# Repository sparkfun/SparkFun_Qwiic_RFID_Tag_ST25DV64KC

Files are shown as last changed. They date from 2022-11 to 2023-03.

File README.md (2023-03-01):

SparkFun Qwiic Dynamic NFC/RFID Tag
===================================

SparkFun Qwiic Dynamic NFC/RFID Tag (https://www.sparkfun.com/products/21274)

[SparkFun Qwiic Dynamic NFC/RFID Tag (SEN-21274)](https://www.sparkfun.com/products/21274)

The STMicroelectronics ST25DV dynamic Near Frequency Communication / Radio Frequency Identification tag ICs are awesome! The ST25DV64KC offers 64-kBit (8-kBytes) of EEPROM memory which can be accessed over both I2C and RF (NFC)! It's a state-of-the-art tag which conforms to ISO/IEC 15693 or NFC Forum Type 5 recommendations. You can read and write the tag's memory using NFC even while the tag is powered down or disconnected!

The EEPROM memory can be divided into four areas, each of which can have different levels of protection applied. Want to store your data so everyone has read and write access over both I2C and RF? You can do that. In fact, that's the default! Want to store your data in an area which can only be read if you know the password, and cannot be written to (via RF)? You can do that too!

Our [Arduino Library](https://github.com/sparkfun/SparkFun_ST25DV64KC_Arduino_Library) provides all of the methods you need to read and write the user memory, control the read and write permissions, alter the area sizes and apply password control. Not only that! We've included extra methods which will let you read and write NDEF (NFC Forum Data Exchange Format) URI, WiFi and Text records which your smart phone can understand!

Repository Contents
-------------------

* /Documents - Data sheets, additional product information
* /Hardware - Eagle design files (.brd, .sch)
* /Production - Production panel files (.brd)

Documentation
-------------

* **[Hookup Guide](https://learn.sparkfun.com/tutorials/qwiic-dynamic-nfcrfid-tag-hookup-guide)** - A basic Hookup Guide for the SparkFun Qwiic Dynamic NFC/RFID Tag.
* **[ST25DV64KC Arduino Library](https://github.com/sparkfun/SparkFun_ST25DV64KC_Arduino_Library)** - Arduino library for the ST25DV64KC Qwiic Dynamic NFC/RFID Tag.
* **[ST25DV64KC Arduino Library Documentation](https://docs.sparkfun.com/SparkFun_ST25DV64KC_Arduino_Library/)** - A full library use overview, API reference guide and key example walk-through.

Product Versions
----------------

* **[SEN-21274](https://www.sparkfun.com/products/21274)** - Initial SparkFun version release
* **[SPX-19035](https://www.sparkfun.com/products/19035)** - Initial SparkX version release

License Information
-------------------

This product is _**open source**_! 

Please review the LICENSE.md file for license information. 

If you have any questions or concerns on licensing, please contact technical support on our [SparkFun forums](https://forum.sparkfun.com/viewforum.php?f=152).

Distributed as-is; no warranty is given.

- Your friends at SparkFun.

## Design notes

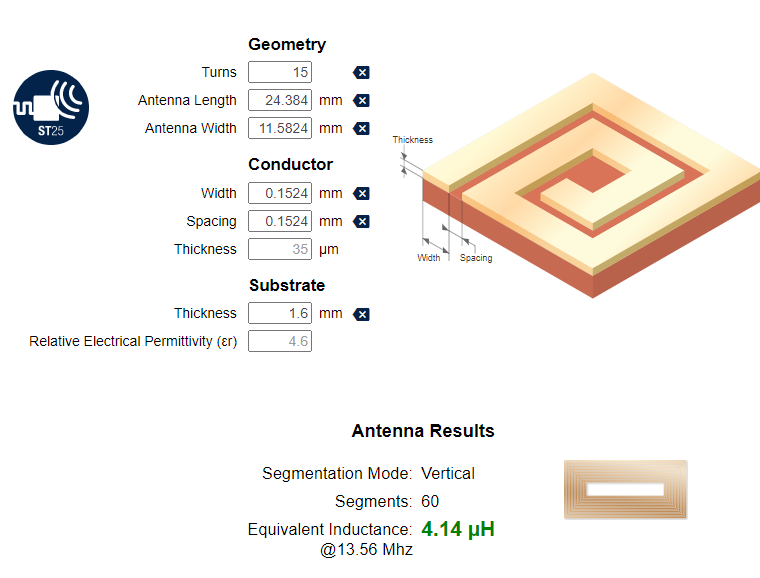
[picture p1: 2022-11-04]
Documents/Antenna_Design.png

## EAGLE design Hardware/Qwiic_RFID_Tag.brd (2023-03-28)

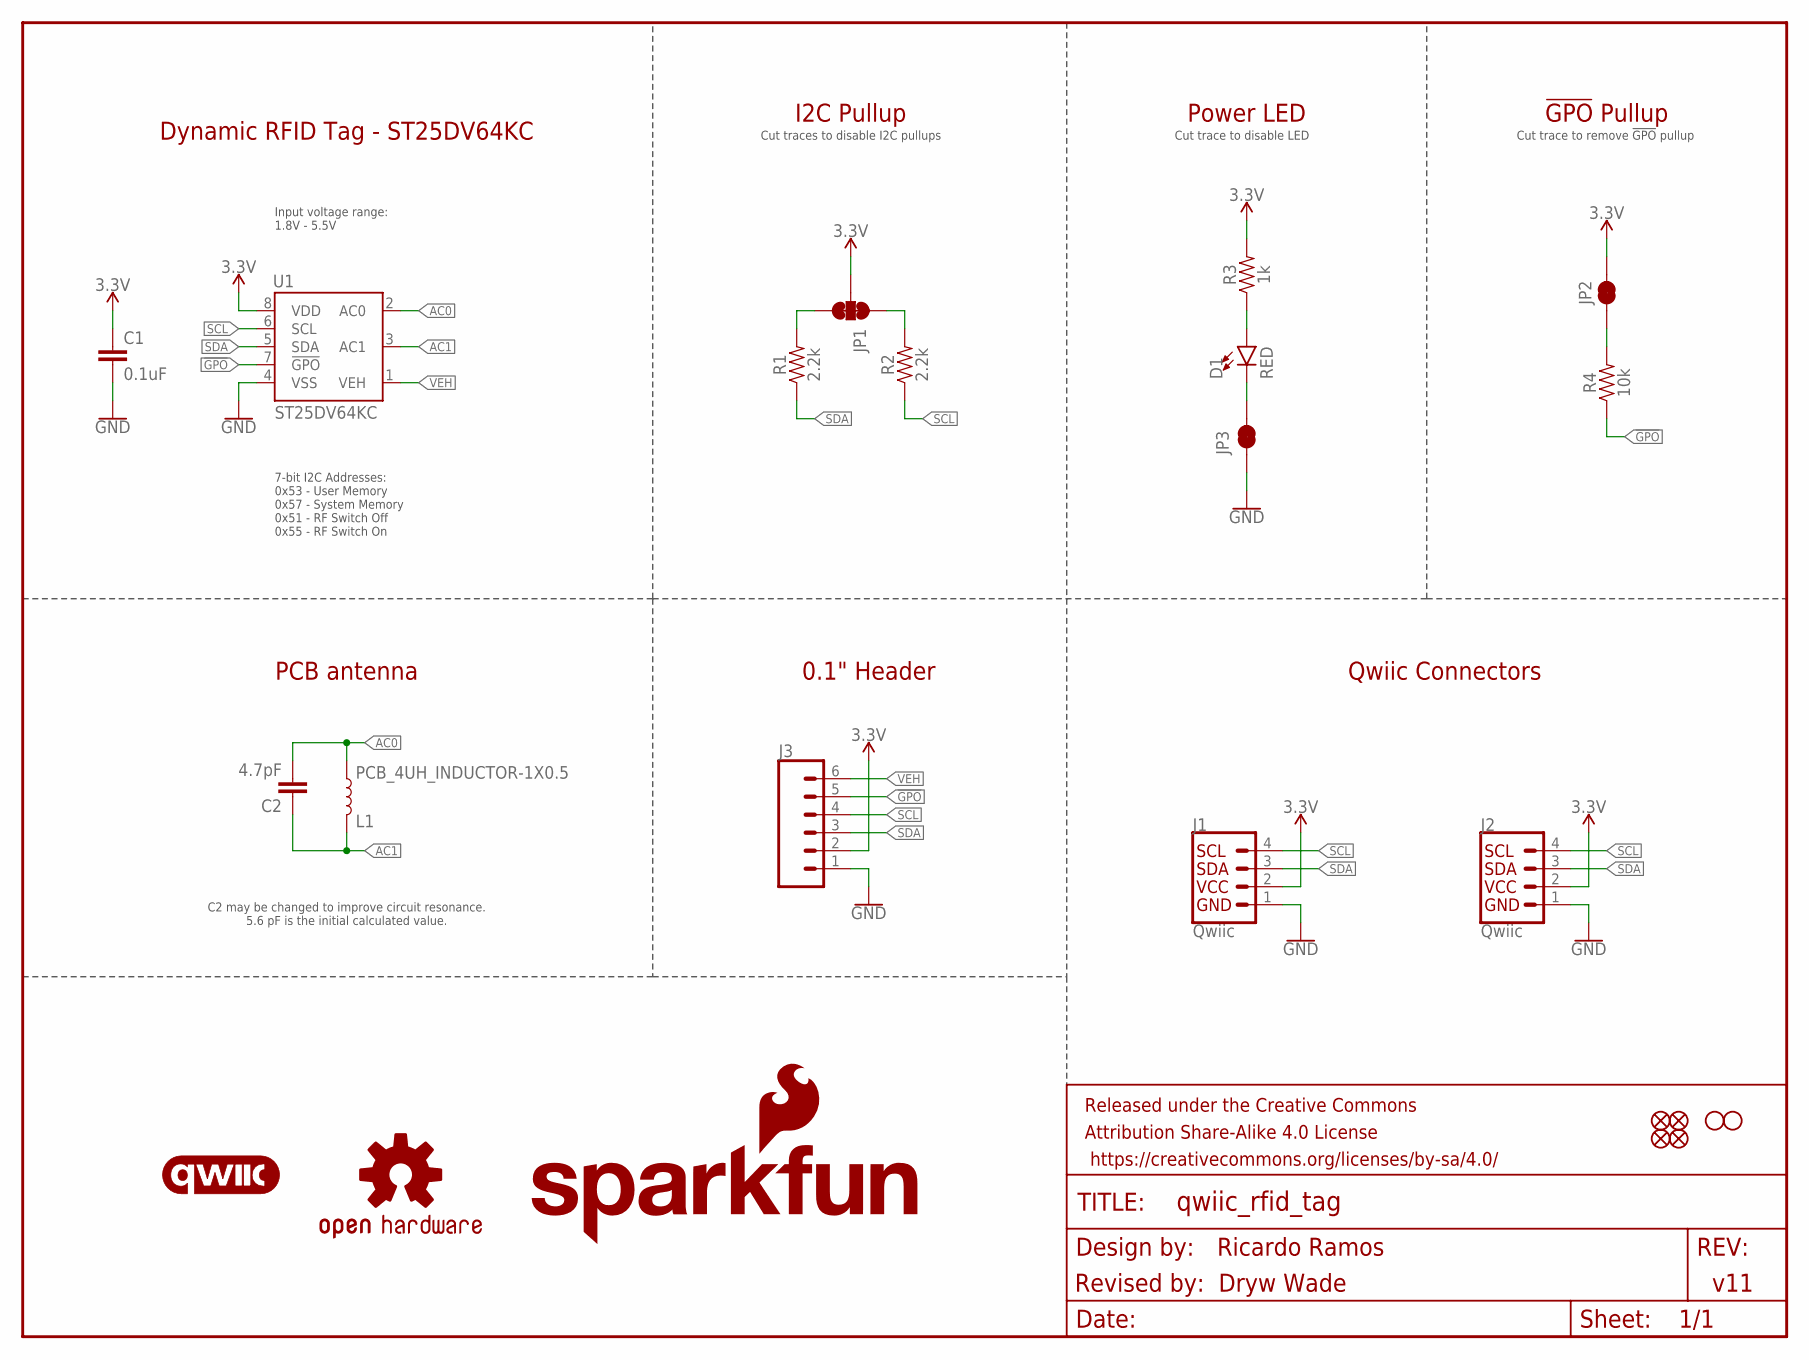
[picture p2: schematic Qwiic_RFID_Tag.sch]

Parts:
C1: 0.1uF; 0603
C2: 4.7pF; 0603
D1: RED; LED-0603
FD1, FD2, FD3, FD4: FIDUCIAL1X2; FIDUCIAL-1X2
FRAME2: FRAME-LETTER; CREATIVE_COMMONS
H3, H4: STAND-OFF
J1, J2: Qwiic; JST04_1MM_RA
J3: CONN_06NO_SILK_FEMALE_PTH; 1X06_NO_SILK
JP1: JUMPER-SMT_3_2-NC_TRACE_SILK; SMT-JUMPER_3_2-NC_TRACE_SILK
JP2, JP3: JUMPER-SMT_2_NC_TRACE_SILK; SMT-JUMPER_2_NC_TRACE_SILK
L1: PCB_4UH_INDUCTOR-1X0.5; PCB_4UH_INDUCTOR_1X0.5
LOGO1: OSHW-LOGOS; OSHW-LOGO-S
LOGO2: SFE_LOGO_NAME_FLAME.1_INCH; SFE_LOGO_NAME_FLAME_.1
LOGO3: QWIIC_LOGO_7MM; QWIIC_7MM
R1, R2: 2.2k; 0603
R3: 1k; 0603
R4: 10k; 0603
U1: ST25DV64KC; SO08

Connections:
3.3V: C1.1, J1.2, J2.2, J3.2, JP1.2, JP2.2, R3.2, U1.8 (VDD)
!GPO!: J3.5, R4.1, U1.7 (!GPO!)
AC0: C2.2, L1.IN2 (2), U1.2 (AC0)
AC1: C2.1, L1.IN1 (1), U1.3 (AC1)
GND: C1.2, J1.1, J2.1, J3.1, JP3.1, U1.4 (VSS)
unnamed: D1.C, JP3.2
unnamed: JP1.3, R1.2
unnamed: JP1.1, R2.2
unnamed: D1.A, R3.1
unnamed: JP2.1, R4.2
SCL: J1.4, J2.4, J3.4, R2.1, U1.6 (SCL)
SDA: J1.3, J2.3, J3.3, R1.1, U1.5 (SDA)
VEH: J3.6, U1.1 (VEH)

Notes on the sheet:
Qwiic Connectors
Cut trace to disable LED
Cut trace to remove !GPO! pullup
0.1" Header
PCB antenna
I2C Pullup
Power LED
!GPO! Pullup
Dynamic RFID Tag - ST25DV64KC
Cut traces to disable I2C pullups
C2 may be changed to improve circuit resonance. 5.6 pF is the initial calculated value.
v11
Ricardo Ramos
Revised by: Dryw Wade
7-bit I2C Addresses: 0x53 - User Memory 0x57 - System Memory 0x51 - RF Switch Off 0x55 - RF Switch On
Input voltage range: 1.8V - 5.5V

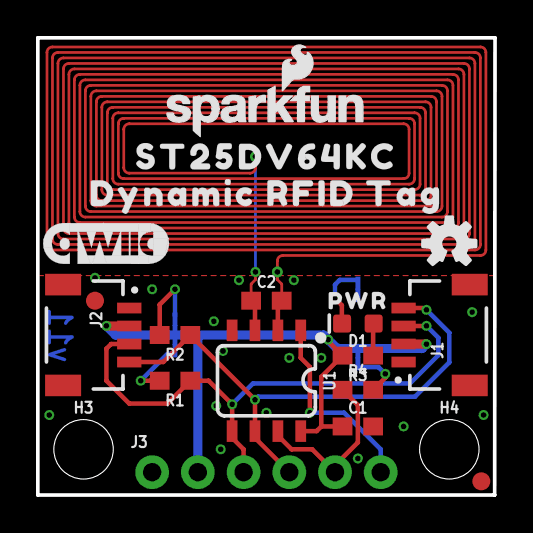
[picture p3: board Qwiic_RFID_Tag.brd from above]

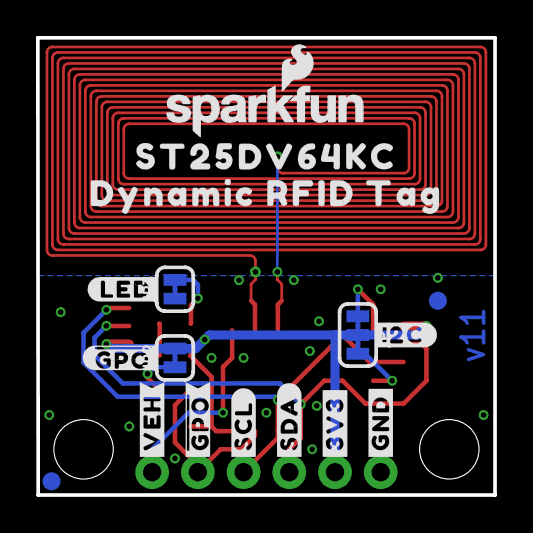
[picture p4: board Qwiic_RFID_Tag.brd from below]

Board: 2 copper layers, 25.4 x 25.4 mm, 40 parts (17 on the bottom side), 13 nets.

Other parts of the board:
LOGO4: SFE_LOGO_NAME_FLAME.1_INCH; SFE_LOGO_NAME_FLAME_.1
U$1: #I2C#0
U$3: #3V3#0
U$9: PWR11
U$10, U$11: DYNAMIC_RFID_TAG0
U$13, U$24: ST25DV64KC5984
U$16: ##GPO##9
U$17: #LED#10
U$18: #GND#4
U$20: #SDA#5
U$21: #SCL#6
U$22: ##GPO##8
U$23: #VEH#7

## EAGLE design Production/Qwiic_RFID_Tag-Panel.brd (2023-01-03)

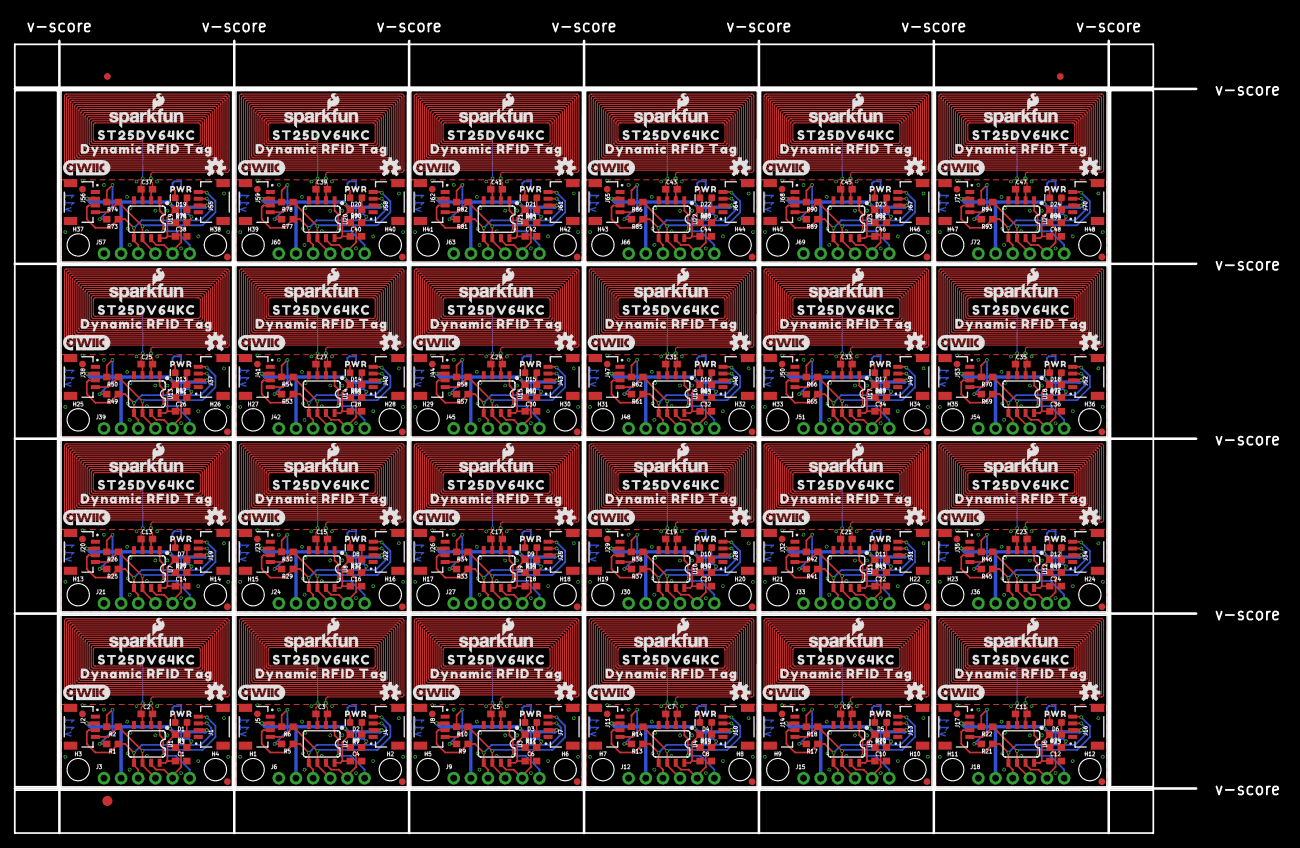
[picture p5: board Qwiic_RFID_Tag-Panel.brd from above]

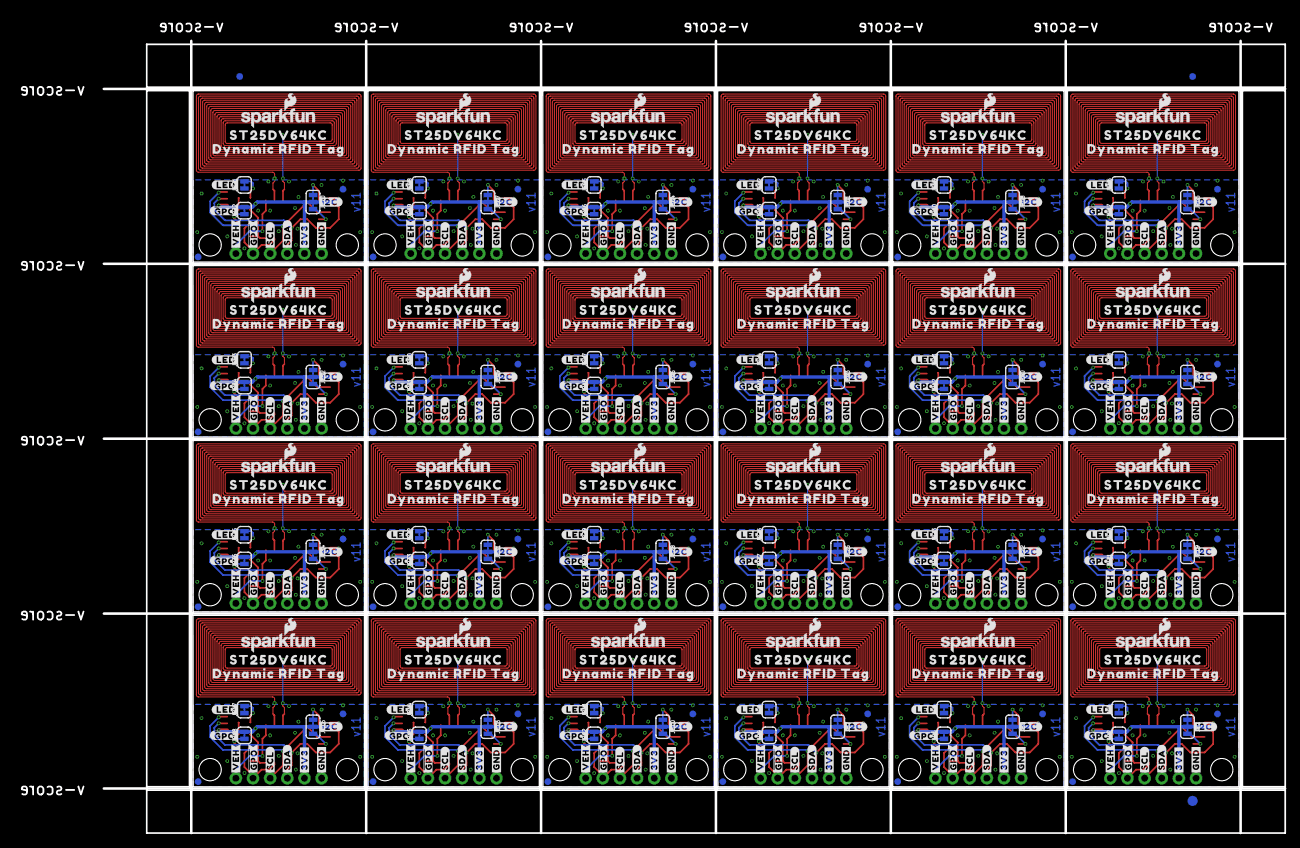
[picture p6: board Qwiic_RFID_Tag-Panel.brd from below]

Board: 2 copper layers, 175.0 x 117.3 mm, 942 parts (411 on the bottom side), 312 nets.

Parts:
C1, C4, C6, C8, C10, C12, C14, C16, C18, C20, C22, C24, C26, C28, C30, C32, C34, C36, C38, C40, C42, C44, C46, C48: 0.1uF; 0603
C2, C3, C5, C7, C9, C11, C13, C15, C17, C19, C21, C23, C25, C27, C29, C31, C33, C35, C37, C39, C41, C43, C45, C47: 4.7pF; 0603
D1, D2, D3, D4, D5, D6, D7, D8, D9, D10, D11, D12, D13, D14, D15, D16, D17, D18, D19, D20, D21, D22, D23, D24: RED; LED-0603
E$1, E$2, E$3, E$4: FIDUCIAL-1X2
E$5, E$6: FIDUCIAL-1.5X3
FD1, FD2, FD3, FD4, FD5, FD6, FD7, FD8, FD9, FD10, FD11, FD12, FD13, FD14, FD15, FD16, FD17, FD18, FD19, FD20, FD21, FD22, FD23, FD24, FD25, FD26, FD27, FD28, FD29, FD30, FD31, FD32, FD33, FD34, FD35, FD36, FD37, FD38, FD39, FD40, FD41, FD42, FD43, FD44, FD45, FD46, FD47, FD48, FD49, FD50, FD51, FD52, FD53, FD54, FD55, FD56, FD57, FD58, FD59, FD60, FD61, FD62, FD63, FD64, FD65, FD66, FD67, FD68, FD69, FD70, FD71, FD72, FD73, FD74, FD75, FD76, FD77, FD78, FD79, FD80, FD81, FD82, FD83, FD84, FD85, FD86, FD87, FD88, FD89, FD90, FD91, FD92, FD93, FD94, FD95, FD96: FIDUCIAL1X2; FIDUCIAL-1X2
H1, H2, H3, H4, H5, H6, H7, H8, H9, H10, H11, H12, H13, H14, H15, H16, H17, H18, H19, H20, H21, H22, H23, H24, H25, H26, H27, H28, H29, H30, H31, H32, H33, H34, H35, H36, H37, H38, H39, H40, H41, H42, H43, H44, H45, H46, H47, H48: STAND-OFF
J1, J2, J4, J5, J7, J8, J10, J11, J13, J14, J16, J17, J19, J20, J22, J23, J25, J26, J28, J29, J31, J32, J34, J35, J37, J38, J40, J41, J43, J44, J46, J47, J49, J50, J52, J53, J55, J56, J58, J59, J61, J62, J64, J65, J67, J68, J70, J71: Qwiic; JST04_1MM_RA
J3, J6, J9, J12, J15, J18, J21, J24, J27, J30, J33, J36, J39, J42, J45, J48, J51, J54, J57, J60, J63, J66, J69, J72: 1X06_NO_SILK
JP1, JP4, JP7, JP10, JP13, JP16, JP19, JP22, JP25, JP28, JP31, JP34, JP37, JP40, JP43, JP46, JP49, JP52, JP55, JP58, JP61, JP64, JP67, JP70: JUMPER-SMT_3_2-NC_TRACE_SILK; SMT-JUMPER_3_2-NC_TRACE_SILK
JP2, JP3, JP5, JP6, JP8, JP9, JP11, JP12, JP14, JP15, JP17, JP18, JP20, JP21, JP23, JP24, JP26, JP27, JP29, JP30, JP32, JP33, JP35, JP36, JP38, JP39, JP41, JP42, JP44, JP45, JP47, JP48, JP50, JP51, JP53, JP54, JP56, JP57, JP59, JP60, JP62, JP63, JP65, JP66, JP68, JP69, JP71, JP72: JUMPER-SMT_2_NC_TRACE_SILK; SMT-JUMPER_2_NC_TRACE_SILK
L1, L2, L3, L4, L5, L6, L7, L8, L9, L10, L11, L12, L13, L14, L15, L16, L17, L18, L19, L20, L21, L22, L23, L24: PCB_COIL_4UH_B
LOGO1, LOGO5, LOGO9, LOGO13, LOGO17, LOGO21, LOGO25, LOGO29, LOGO33, LOGO37, LOGO41, LOGO45, LOGO49, LOGO53, LOGO57, LOGO61, LOGO65, LOGO69, LOGO73, LOGO77, LOGO81, LOGO85, LOGO89, LOGO93: OSHW-LOGOS; OSHW-LOGO-S
LOGO2, LOGO4, LOGO7, LOGO8, LOGO11, LOGO12, LOGO15, LOGO16, LOGO19, LOGO20, LOGO23, LOGO24, LOGO27, LOGO28, LOGO31, LOGO32, LOGO35, LOGO36, LOGO39, LOGO40, LOGO43, LOGO44, LOGO47, LOGO48, LOGO51, LOGO52, LOGO55, LOGO56, LOGO59, LOGO60, LOGO63, LOGO64, LOGO67, LOGO68, LOGO71, LOGO72, LOGO75, LOGO76, LOGO79, LOGO80, LOGO83, LOGO84, LOGO87, LOGO88, LOGO91, LOGO92, LOGO95, LOGO96: SFE_LOGO_NAME_FLAME.1_INCH; SFE_LOGO_NAME_FLAME_.1
LOGO3, LOGO6, LOGO10, LOGO14, LOGO18, LOGO22, LOGO26, LOGO30, LOGO34, LOGO38, LOGO42, LOGO46, LOGO50, LOGO54, LOGO58, LOGO62, LOGO66, LOGO70, LOGO74, LOGO78, LOGO82, LOGO86, LOGO90, LOGO94: QWIIC_LOGO_7MM; QWIIC_7MM
R1, R2, R5, R6, R9, R10, R13, R14, R17, R18, R21, R22, R25, R26, R29, R30, R33, R34, R37, R38, R41, R42, R45, R46, R49, R50, R53, R54, R57, R58, R61, R62, R65, R66, R69, R70, R73, R74, R77, R78, R81, R82, R85, R86, R89, R90, R93, R94: 2.2k; 0603
R3, R7, R11, R15, R19, R23, R27, R31, R35, R39, R43, R47, R51, R55, R59, R63, R67, R71, R75, R79, R83, R87, R91, R95: 1k; 0603
R4, R8, R12, R16, R20, R24, R28, R32, R36, R40, R44, R48, R52, R56, R60, R64, R68, R72, R76, R80, R84, R88, R92, R96: 10k; 0603
U1, U2, U3, U4, U5, U6, U7, U8, U9, U10, U11, U12, U13, U14, U15, U16, U17, U18, U19, U20, U21, U22, U23, U24: ST25DV64KC; SO08
U$1, U$27, U$41, U$55, U$69, U$83, U$97, U$111, U$125, U$139, U$153, U$167, U$181, U$195, U$209, U$223, U$237, U$251, U$265, U$279, U$293, U$307, U$321, U$335: #I2C#0
U$2, U$9, U$29, U$43, U$57, U$71, U$85, U$99, U$113, U$127, U$141, U$155, U$169, U$183, U$197, U$211, U$225, U$239, U$253, U$267, U$281, U$295, U$309, U$323: PWR11
U$3, U$28, U$42, U$56, U$70, U$84, U$98, U$112, U$126, U$140, U$154, U$168, U$182, U$196, U$210, U$224, U$238, U$252, U$266, U$280, U$294, U$308, U$322, U$336: #3V3#0
U$4, U$16, U$30, U$44, U$58, U$72, U$86, U$100, U$114, U$128, U$142, U$156, U$170, U$184, U$198, U$212, U$226, U$240, U$254, U$268, U$282, U$296, U$310, U$324: ##GPO##9
U$5, U$17, U$31, U$45, U$59, U$73, U$87, U$101, U$115, U$129, U$143, U$157, U$171, U$185, U$199, U$213, U$227, U$241, U$255, U$269, U$283, U$297, U$311, U$325: #LED#10
U$6, U$18, U$32, U$46, U$60, U$74, U$88, U$102, U$116, U$130, U$144, U$158, U$172, U$186, U$200, U$214, U$228, U$242, U$256, U$270, U$284, U$298, U$312, U$326: #GND#4
U$7, U$20, U$33, U$47, U$61, U$75, U$89, U$103, U$117, U$131, U$145, U$159, U$173, U$187, U$201, U$215, U$229, U$243, U$257, U$271, U$285, U$299, U$313, U$327: #SDA#5
U$8, U$21, U$34, U$48, U$62, U$76, U$90, U$104, U$118, U$132, U$146, U$160, U$174, U$188, U$202, U$216, U$230, U$244, U$258, U$272, U$286, U$300, U$314, U$328: #SCL#6
U$10, U$11, U$25, U$26, U$39, U$40, U$53, U$54, U$67, U$68, U$81, U$82, U$95, U$96, U$109, U$110, U$123, U$124, U$137, U$138, U$151, U$152, U$165, U$166, U$179, U$180, U$193, U$194, U$207, U$208, U$221, U$222, U$235, U$236, U$249, U$250, U$263, U$264, U$277, U$278, U$291, U$292, U$305, U$306, U$319, U$320, U$333, U$334: DYNAMIC_RFID_TAG0
U$12, U$22, U$35, U$49, U$63, U$77, U$91, U$105, U$119, U$133, U$147, U$161, U$175, U$189, U$203, U$217, U$231, U$245, U$259, U$273, U$287, U$301, U$315, U$329: ##GPO##8
U$13, U$15, U$19, U$24, U$37, U$38, U$51, U$52, U$65, U$66, U$79, U$80, U$93, U$94, U$107, U$108, U$121, U$122, U$135, U$136, U$149, U$150, U$163, U$164, U$177, U$178, U$191, U$192, U$205, U$206, U$219, U$220, U$233, U$234, U$247, U$248, U$261, U$262, U$275, U$276, U$289, U$290, U$303, U$304, U$317, U$318, U$331, U$332: ST25DV64KC5984
U$14, U$23, U$36, U$50, U$64, U$78, U$92, U$106, U$120, U$134, U$148, U$162, U$176, U$190, U$204, U$218, U$232, U$246, U$260, U$274, U$288, U$302, U$316, U$330: #VEH#7

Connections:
3.3V: C1.1, J1.2, J2.2, J3.2, JP1.2, JP2.2, R3.2, U1.8
3.3V1: C4.1, J4.2, J5.2, J6.2, JP4.2, JP6.2, R7.2, U2.8
3.3V2: C6.1, J7.2, J8.2, J9.2, JP7.2, JP9.2, R11.2, U3.8
3.3V3: C8.1, J10.2, J11.2, J12.2, JP10.2, JP12.2, R15.2, U4.8
3.3V4: C10.1, J13.2, J14.2, J15.2, JP13.2, JP15.2, R19.2, U5.8
3.3V5: C12.1, J16.2, J17.2, J18.2, JP16.2, JP18.2, R23.2, U6.8
3.3V6: C14.1, J19.2, J20.2, J21.2, JP19.2, JP21.2, R27.2, U7.8
3.3V7: C16.1, J22.2, J23.2, J24.2, JP22.2, JP24.2, R31.2, U8.8
3.3V8: C18.1, J25.2, J26.2, J27.2, JP25.2, JP27.2, R35.2, U9.8
3.3V9: C20.1, J28.2, J29.2, J30.2, JP28.2, JP30.2, R39.2, U10.8
3.3V10: C22.1, J31.2, J32.2, J33.2, JP31.2, JP33.2, R43.2, U11.8
3.3V11: C24.1, J34.2, J35.2, J36.2, JP34.2, JP36.2, R47.2, U12.8
3.3V12: C26.1, J37.2, J38.2, J39.2, JP37.2, JP39.2, R51.2, U13.8
3.3V13: C28.1, J40.2, J41.2, J42.2, JP40.2, JP42.2, R55.2, U14.8
3.3V14: C30.1, J43.2, J44.2, J45.2, JP43.2, JP45.2, R59.2, U15.8
3.3V15: C32.1, J46.2, J47.2, J48.2, JP46.2, JP48.2, R63.2, U16.8
3.3V16: C34.1, J49.2, J50.2, J51.2, JP49.2, JP51.2, R67.2, U17.8
3.3V17: C36.1, J52.2, J53.2, J54.2, JP52.2, JP54.2, R71.2, U18.8
3.3V18: C38.1, J55.2, J56.2, J57.2, JP55.2, JP57.2, R75.2, U19.8
3.3V19: C40.1, J58.2, J59.2, J60.2, JP58.2, JP60.2, R79.2, U20.8
3.3V20: C42.1, J61.2, J62.2, J63.2, JP61.2, JP63.2, R83.2, U21.8
3.3V21: C44.1, J64.2, J65.2, J66.2, JP64.2, JP66.2, R87.2, U22.8
3.3V22: C46.1, J67.2, J68.2, J69.2, JP67.2, JP69.2, R91.2, U23.8
3.3V23: C48.1, J70.2, J71.2, J72.2, JP70.2, JP72.2, R95.2, U24.8
!GPO!: J3.5, R4.1, U1.7
!GPO!1: J6.5, R8.1, U2.7
!GPO!2: J9.5, R12.1, U3.7
!GPO!3: J12.5, R16.1, U4.7
!GPO!4: J15.5, R20.1, U5.7
!GPO!5: J18.5, R24.1, U6.7
!GPO!6: J21.5, R28.1, U7.7
!GPO!7: J24.5, R32.1, U8.7
!GPO!8: J27.5, R36.1, U9.7
!GPO!9: J30.5, R40.1, U10.7
!GPO!10: J33.5, R44.1, U11.7
!GPO!11: J36.5, R48.1, U12.7
!GPO!12: J39.5, R52.1, U13.7
!GPO!13: J42.5, R56.1, U14.7
!GPO!14: J45.5, R60.1, U15.7
!GPO!15: J48.5, R64.1, U16.7
!GPO!16: J51.5, R68.1, U17.7
!GPO!17: J54.5, R72.1, U18.7
!GPO!18: J57.5, R76.1, U19.7
!GPO!19: J60.5, R80.1, U20.7
!GPO!20: J63.5, R84.1, U21.7
!GPO!21: J66.5, R88.1, U22.7
!GPO!22: J69.5, R92.1, U23.7
!GPO!23: J72.5, R96.1, U24.7
AC0: C2.2, L1.IN2, U1.2
AC1: C2.1, L1.IN1, U1.3
AC2: C3.2, L2.IN2, U2.2
AC3: C3.1, L2.IN1, U2.3
AC4: C5.2, L3.IN2, U3.2
AC5: C5.1, L3.IN1, U3.3
AC6: C7.2, L4.IN2, U4.2
AC7: C7.1, L4.IN1, U4.3
AC8: C9.2, L5.IN2, U5.2
AC9: C9.1, L5.IN1, U5.3
AC10: C11.2, L6.IN2, U6.2
AC11: C11.1, L6.IN1, U6.3
AC12: C13.2, L7.IN2, U7.2
AC13: C13.1, L7.IN1, U7.3
AC14: C15.2, L8.IN2, U8.2
AC15: C15.1, L8.IN1, U8.3
AC16: C17.2, L9.IN2, U9.2
AC17: C17.1, L9.IN1, U9.3
AC18: C19.2, L10.IN2, U10.2
AC19: C19.1, L10.IN1, U10.3
AC20: C21.2, L11.IN2, U11.2
AC21: C21.1, L11.IN1, U11.3
AC22: C23.2, L12.IN2, U12.2
AC23: C23.1, L12.IN1, U12.3
AC24: C25.2, L13.IN2, U13.2
AC25: C25.1, L13.IN1, U13.3
AC26: C27.2, L14.IN2, U14.2
AC27: C27.1, L14.IN1, U14.3
AC28: C29.2, L15.IN2, U15.2
AC29: C29.1, L15.IN1, U15.3
AC30: C31.2, L16.IN2, U16.2
AC31: C31.1, L16.IN1, U16.3
AC32: C33.2, L17.IN2, U17.2
AC33: C33.1, L17.IN1, U17.3
AC34: C35.2, L18.IN2, U18.2
AC35: C35.1, L18.IN1, U18.3
AC36: C37.2, L19.IN2, U19.2
AC37: C37.1, L19.IN1, U19.3
AC38: C39.2, L20.IN2, U20.2
AC39: C39.1, L20.IN1, U20.3
AC40: C41.2, L21.IN2, U21.2
AC41: C41.1, L21.IN1, U21.3
AC42: C43.2, L22.IN2, U22.2
AC43: C43.1, L22.IN1, U22.3
AC44: C45.2, L23.IN2, U23.2
AC45: C45.1, L23.IN1, U23.3
AC46: C47.2, L24.IN2, U24.2
AC47: C47.1, L24.IN1, U24.3
GND: C1.2, J1.1, J2.1, J3.1, JP3.1, U1.4
GND1: C4.2, J4.1, J5.1, J6.1, JP5.1, U2.4
GND2: C6.2, J7.1, J8.1, J9.1, JP8.1, U3.4
GND3: C8.2, J10.1, J11.1, J12.1, JP11.1, U4.4
GND4: C10.2, J13.1, J14.1, J15.1, JP14.1, U5.4
GND5: C12.2, J16.1, J17.1, J18.1, JP17.1, U6.4
GND6: C14.2, J19.1, J20.1, J21.1, JP20.1, U7.4
GND7: C16.2, J22.1, J23.1, J24.1, JP23.1, U8.4
GND8: C18.2, J25.1, J26.1, J27.1, JP26.1, U9.4
GND9: C20.2, J28.1, J29.1, J30.1, JP29.1, U10.4
GND10: C22.2, J31.1, J32.1, J33.1, JP32.1, U11.4
GND11: C24.2, J34.1, J35.1, J36.1, JP35.1, U12.4
GND12: C26.2, J37.1, J38.1, J39.1, JP38.1, U13.4
GND13: C28.2, J40.1, J41.1, J42.1, JP41.1, U14.4
GND14: C30.2, J43.1, J44.1, J45.1, JP44.1, U15.4
GND15: C32.2, J46.1, J47.1, J48.1, JP47.1, U16.4
GND16: C34.2, J49.1, J50.1, J51.1, JP50.1, U17.4
GND17: C36.2, J52.1, J53.1, J54.1, JP53.1, U18.4
GND18: C38.2, J55.1, J56.1, J57.1, JP56.1, U19.4
GND19: C40.2, J58.1, J59.1, J60.1, JP59.1, U20.4
GND20: C42.2, J61.1, J62.1, J63.1, JP62.1, U21.4
GND21: C44.2, J64.1, J65.1, J66.1, JP65.1, U22.4
GND22: C46.2, J67.1, J68.1, J69.1, JP68.1, U23.4
GND23: C48.2, J70.1, J71.1, J72.1, JP71.1, U24.4
unnamed: D1.C, JP3.2
unnamed: JP1.3, R1.2
unnamed: JP1.1, R2.2
unnamed: D1.A, R3.1
unnamed: JP2.1, R4.2
unnamed: JP4.3, R5.2
unnamed: JP4.1, R6.2
unnamed: D2.A, R7.1
unnamed: JP6.1, R8.2
unnamed: D2.C, JP5.2
unnamed: JP7.3, R9.2
unnamed: JP7.1, R10.2
unnamed: D3.A, R11.1
unnamed: JP9.1, R12.2
unnamed: D3.C, JP8.2
unnamed: JP10.3, R13.2
unnamed: JP10.1, R14.2
unnamed: D4.A, R15.1
unnamed: JP12.1, R16.2
unnamed: D4.C, JP11.2
unnamed: JP13.3, R17.2
unnamed: JP13.1, R18.2
unnamed: D5.A, R19.1
unnamed: JP15.1, R20.2
unnamed: D5.C, JP14.2
unnamed: JP16.3, R21.2
unnamed: JP16.1, R22.2
unnamed: D6.A, R23.1
unnamed: JP18.1, R24.2
unnamed: D6.C, JP17.2
unnamed: JP19.3, R25.2
unnamed: JP19.1, R26.2
unnamed: D7.A, R27.1
unnamed: JP21.1, R28.2
unnamed: D7.C, JP20.2
unnamed: JP22.3, R29.2
unnamed: JP22.1, R30.2
unnamed: D8.A, R31.1
unnamed: JP24.1, R32.2
unnamed: D8.C, JP23.2
unnamed: JP25.3, R33.2
unnamed: JP25.1, R34.2
unnamed: D9.A, R35.1
unnamed: JP27.1, R36.2
unnamed: D9.C, JP26.2
unnamed: JP28.3, R37.2
unnamed: JP28.1, R38.2
unnamed: D10.A, R39.1
unnamed: JP30.1, R40.2
unnamed: D10.C, JP29.2
unnamed: JP31.3, R41.2
unnamed: JP31.1, R42.2
unnamed: D11.A, R43.1
unnamed: JP33.1, R44.2
unnamed: D11.C, JP32.2
unnamed: JP34.3, R45.2
unnamed: JP34.1, R46.2
unnamed: D12.A, R47.1
unnamed: JP36.1, R48.2
unnamed: D12.C, JP35.2
unnamed: JP37.3, R49.2
unnamed: JP37.1, R50.2
unnamed: D13.A, R51.1
unnamed: JP39.1, R52.2
unnamed: D13.C, JP38.2
unnamed: JP40.3, R53.2
unnamed: JP40.1, R54.2
unnamed: D14.A, R55.1
unnamed: JP42.1, R56.2
unnamed: D14.C, JP41.2
unnamed: JP43.3, R57.2
unnamed: JP43.1, R58.2
unnamed: D15.A, R59.1
unnamed: JP45.1, R60.2
unnamed: D15.C, JP44.2
unnamed: JP46.3, R61.2
unnamed: JP46.1, R62.2
unnamed: D16.A, R63.1
unnamed: JP48.1, R64.2
unnamed: D16.C, JP47.2
unnamed: JP49.3, R65.2
unnamed: JP49.1, R66.2
unnamed: D17.A, R67.1
unnamed: JP51.1, R68.2
unnamed: D17.C, JP50.2
unnamed: JP52.3, R69.2
unnamed: JP52.1, R70.2
unnamed: D18.A, R71.1
unnamed: JP54.1, R72.2
unnamed: D18.C, JP53.2
unnamed: JP55.3, R73.2
unnamed: JP55.1, R74.2
unnamed: D19.A, R75.1
unnamed: JP57.1, R76.2
unnamed: D19.C, JP56.2
unnamed: JP58.3, R77.2
unnamed: JP58.1, R78.2
unnamed: D20.A, R79.1
unnamed: JP60.1, R80.2
unnamed: D20.C, JP59.2
unnamed: JP61.3, R81.2
unnamed: JP61.1, R82.2
unnamed: D21.A, R83.1
unnamed: JP63.1, R84.2
unnamed: D21.C, JP62.2
unnamed: JP64.3, R85.2
unnamed: JP64.1, R86.2
unnamed: D22.A, R87.1
unnamed: JP66.1, R88.2
unnamed: D22.C, JP65.2
unnamed: JP67.3, R89.2
unnamed: JP67.1, R90.2
unnamed: D23.A, R91.1
unnamed: JP69.1, R92.2
unnamed: D23.C, JP68.2
unnamed: JP70.3, R93.2
unnamed: JP70.1, R94.2
unnamed: D24.A, R95.1
unnamed: JP72.1, R96.2
unnamed: D24.C, JP71.2
SCL: J1.4, J2.4, J3.4, R2.1, U1.6
SCL1: J4.4, J5.4, J6.4, R6.1, U2.6
SCL2: J7.4, J8.4, J9.4, R10.1, U3.6
SCL3: J10.4, J11.4, J12.4, R14.1, U4.6
SCL4: J13.4, J14.4, J15.4, R18.1, U5.6
SCL5: J16.4, J17.4, J18.4, R22.1, U6.6
SCL6: J19.4, J20.4, J21.4, R26.1, U7.6
SCL7: J22.4, J23.4, J24.4, R30.1, U8.6
SCL8: J25.4, J26.4, J27.4, R34.1, U9.6
SCL9: J28.4, J29.4, J30.4, R38.1, U10.6
SCL10: J31.4, J32.4, J33.4, R42.1, U11.6
SCL11: J34.4, J35.4, J36.4, R46.1, U12.6
SCL12: J37.4, J38.4, J39.4, R50.1, U13.6
SCL13: J40.4, J41.4, J42.4, R54.1, U14.6
SCL14: J43.4, J44.4, J45.4, R58.1, U15.6
SCL15: J46.4, J47.4, J48.4, R62.1, U16.6
SCL16: J49.4, J50.4, J51.4, R66.1, U17.6
SCL17: J52.4, J53.4, J54.4, R70.1, U18.6
SCL18: J55.4, J56.4, J57.4, R74.1, U19.6
SCL19: J58.4, J59.4, J60.4, R78.1, U20.6
SCL20: J61.4, J62.4, J63.4, R82.1, U21.6
SCL21: J64.4, J65.4, J66.4, R86.1, U22.6
SCL22: J67.4, J68.4, J69.4, R90.1, U23.6
SCL23: J70.4, J71.4, J72.4, R94.1, U24.6
SDA: J1.3, J2.3, J3.3, R1.1, U1.5
SDA1: J4.3, J5.3, J6.3, R5.1, U2.5
SDA2: J7.3, J8.3, J9.3, R9.1, U3.5
SDA3: J10.3, J11.3, J12.3, R13.1, U4.5
SDA4: J13.3, J14.3, J15.3, R17.1, U5.5
SDA5: J16.3, J17.3, J18.3, R21.1, U6.5
SDA6: J19.3, J20.3, J21.3, R25.1, U7.5
SDA7: J22.3, J23.3, J24.3, R29.1, U8.5
SDA8: J25.3, J26.3, J27.3, R33.1, U9.5
SDA9: J28.3, J29.3, J30.3, R37.1, U10.5
SDA10: J31.3, J32.3, J33.3, R41.1, U11.5
SDA11: J34.3, J35.3, J36.3, R45.1, U12.5
SDA12: J37.3, J38.3, J39.3, R49.1, U13.5
SDA13: J40.3, J41.3, J42.3, R53.1, U14.5
SDA14: J43.3, J44.3, J45.3, R57.1, U15.5
SDA15: J46.3, J47.3, J48.3, R61.1, U16.5
SDA16: J49.3, J50.3, J51.3, R65.1, U17.5
SDA17: J52.3, J53.3, J54.3, R69.1, U18.5
SDA18: J55.3, J56.3, J57.3, R73.1, U19.5
SDA19: J58.3, J59.3, J60.3, R77.1, U20.5
SDA20: J61.3, J62.3, J63.3, R81.1, U21.5
SDA21: J64.3, J65.3, J66.3, R85.1, U22.5
SDA22: J67.3, J68.3, J69.3, R89.1, U23.5
SDA23: J70.3, J71.3, J72.3, R93.1, U24.5
VEH: J3.6, U1.1
VEH1: J6.6, U2.1
VEH2: J9.6, U3.1
VEH3: J12.6, U4.1
VEH4: J15.6, U5.1
VEH5: J18.6, U6.1
VEH6: J21.6, U7.1
VEH7: J24.6, U8.1
VEH8: J27.6, U9.1
VEH9: J30.6, U10.1
VEH10: J33.6, U11.1
VEH11: J36.6, U12.1
VEH12: J39.6, U13.1
VEH13: J42.6, U14.1
VEH14: J45.6, U15.1
VEH15: J48.6, U16.1
VEH16: J51.6, U17.1
VEH17: J54.6, U18.1
VEH18: J57.6, U19.1
VEH19: J60.6, U20.1
VEH20: J63.6, U21.1
VEH21: J66.6, U22.1
VEH22: J69.6, U23.1
VEH23: J72.6, U24.1

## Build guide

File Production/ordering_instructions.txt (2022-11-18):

panel size, 169x117mm
PCB thickness, 1.6mm
number of layers, 2
soldermask color, Red
silkscreen color, White
oz copper, 1oz
finish, HASL lead free
stencils, top
pcs per panel, 24
min trace width, 0.1524mm / 0.0060in
min drill size, 0.3048mm / 0.0120in

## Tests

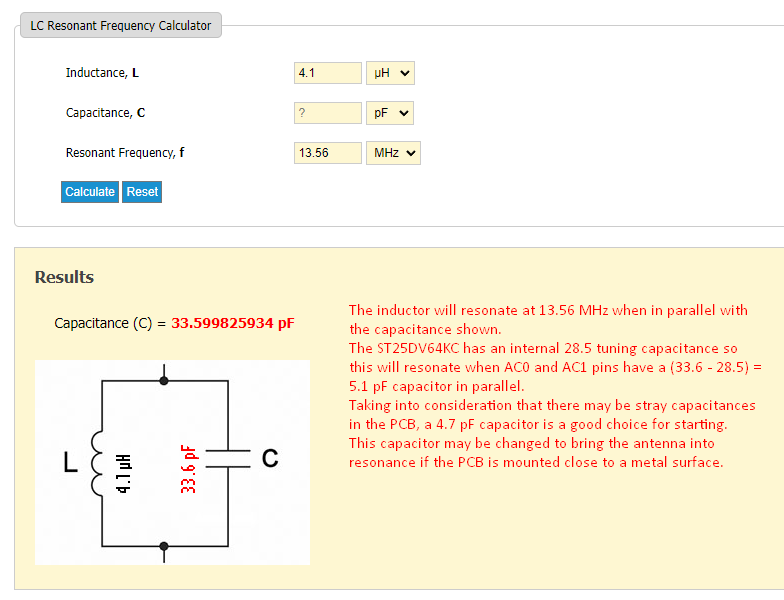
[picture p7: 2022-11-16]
Documents/Antenna_Tuning.png

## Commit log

2022-11-04 Add antenna variants
2022-11-04 Add initial board variants
    Includes one 1x2 board, and two 1x1 board options. Will run protos of each
    [Qwiic_RFID_Tag_A.brd, Qwiic_RFID_Tag_A.sch, Qwiic_RFID_Tag_B.brd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]
2022-11-04 Update aesthetics
    Add SFE logo
    Update version number
    Change schematic frame to correct version
    Update design attribution
    [Qwiic_RFID_Tag_A.brd, Qwiic_RFID_Tag_A.sch, Qwiic_RFID_Tag_B.brd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]
2022-11-07 Design review updates
    All scehmatics:
    Change IC text to “Dynamic RFID Tag - ST25DV64KC”
    Move decoupling capacitor near IC
    Update I2C jumper text to say "traces" instead of "trace"
    Version A board:
    Fix stray via diameter
    Approve jumper overlap error
    Version C board:
    Add SFE logo to bottom silk
    [Qwiic_RFID_Tag_A.brd, Qwiic_RFID_Tag_A.sch, Qwiic_RFID_Tag_B.brd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]
2022-11-07 Design review updates
    Add version letter to silk
    Add I2C addresses to schematic
    Change PTH silk labels from "3.3V" to "3V3"
    [Qwiic_RFID_Tag_A.brd, Qwiic_RFID_Tag_A.sch, Qwiic_RFID_Tag_B.brd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]
2022-11-16 v10 Updates
    Remove A and C versions, moving forward with B
    Reorganize hardware folder
    Rename coil library to match SFE library naming
    Bump version number to v10
    Smash power symbols to get vector font
    [Qwiic_RFID_Tag.brd, Qwiic_RFID_Tag.sch, Qwiic_RFID_Tag_B.brd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]
2022-11-18 Add input voltage range
    [Qwiic_RFID_Tag.brd, Qwiic_RFID_Tag.sch]
2022-11-18 Add v10 panel
    [Qwiic_RFID_Tag-Panel.GBL, Qwiic_RFID_Tag-Panel.GBO, Qwiic_RFID_Tag-Panel.GBP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]
2023-01-03 Bump version number to v11 and repanelize
    Panelizer didn't work correctly on v10, none of the pads had nets assigned to them, so the GND polygon didn't connect to any GND pads. Repanlizing seems to fix it? Idk, it's whacky.
    [Qwiic_RFID_Tag-Panel.brd, Qwiic_RFID_Tag.brd, Qwiic_RFID_Tag.sch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]
2023-03-28 Remove library file
    Part is in SFE Eagle library, update part in design
    [Qwiic_RFID_Tag.brd, Qwiic_RFID_Tag.sch]

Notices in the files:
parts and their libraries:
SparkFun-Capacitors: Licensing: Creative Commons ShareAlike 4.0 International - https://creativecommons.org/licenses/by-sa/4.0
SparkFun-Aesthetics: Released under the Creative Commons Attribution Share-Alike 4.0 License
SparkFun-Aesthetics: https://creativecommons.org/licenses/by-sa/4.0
